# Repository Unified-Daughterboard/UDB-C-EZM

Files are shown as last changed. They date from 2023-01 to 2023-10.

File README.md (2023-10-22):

# Unified Daughterboard C Series - EZM variant

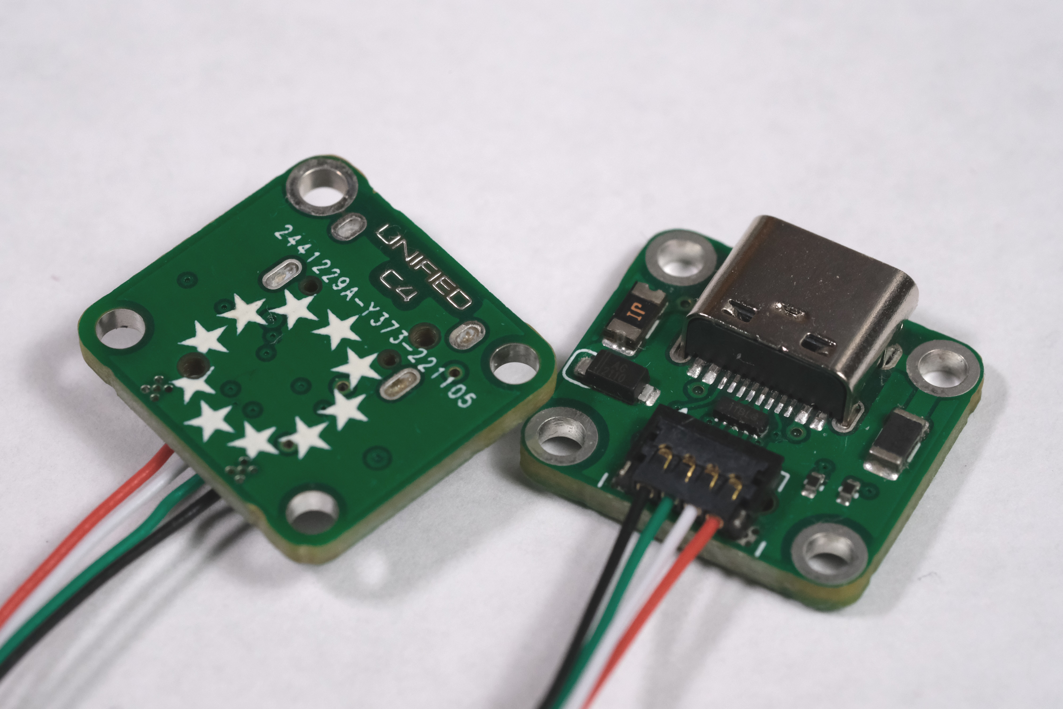
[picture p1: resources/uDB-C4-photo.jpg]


## Introduction
The Unified Daughterboard Project is an open standard to unify the USB daughterboards used in custom mechanical keyboard projects.  
The Unified Daughterboard allows designers to easily implementing electrical protection via a tested proven PCB, and allows users to maintain and repair their keyboards in the future.  
  
For more details on the Unified Daughterboard project, see the [main website](https://unified-daughterboard.github.io/).

## C Series

The C5 daughterboard is the current most recent revision to the classic square form-factor daughterboard, with its roots in the C1 which was designed to be compatible with Wilba's keyboards.
The daughterboard features the following:

- ESD protection, overcurrent protection, overvoltage protection, shielding noise decoupling, and single-path grounding to chassis functionality
- Two variants: The new Molex Pico-EZmate and the classic JST-SH
- 1:1 connector pinout to retain compatibility with existing PCBs
- Same form factor as the older C3 series, allowing for daughterboard upgrades
  
**This is the EZM variant using the Pico-EZMate connector.**  
For background on why two variants exist, please see the [announcement post](https://unified-daughterboard.github.io/#/announcements/announcement-20231022).

The C5 version of the daughterboard was split into two versions: C-JSH and C-PEM, repectively pertaining to versions using the JST-SH connector and the MOLEX EZMate connector.

## Using the C series uDB in your design
Please [visit the docs](https://unified-daughterboard.github.io/) for detailed implementation references and notices.  

## Previews
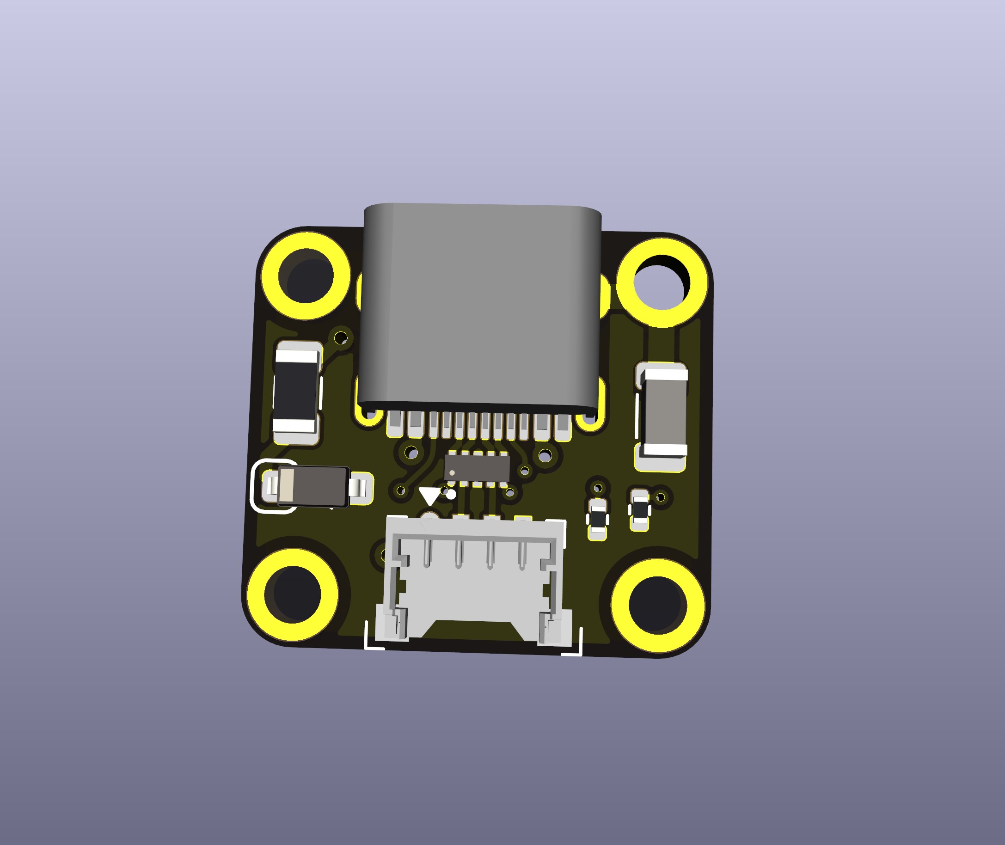
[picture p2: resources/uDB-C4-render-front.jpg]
Render

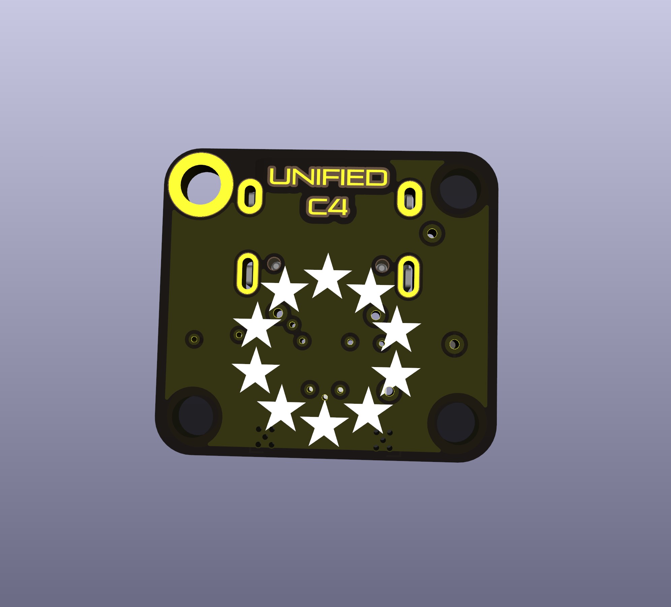
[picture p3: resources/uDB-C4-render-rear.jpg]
Render


## Credits
- [Gondolindrim](https://github.com/Gondolindrim)
- [hineybush](https://hineybush.com/)
- [ai03](https://ai03.com/)
- [GEON](https://geon.works/)
- [Sleepdealer](https://sleepdealer.xyz)
- [Xelus](https://xelus.me)
- [James (AKB)](https://alchemistkeyboards.com/)
- [kkatano](https://github.com/kkatano)
- [ToastyStoemp](https://vwolf.be)
- [Upas](https://cannonkeys.com)

C3 Unified:
- [Wilba](https://wilba.tech)
- Xondat
- [aeryxz](https://github.com/aeryxz)
- [Maximillian](https://github.com/Maximillian)

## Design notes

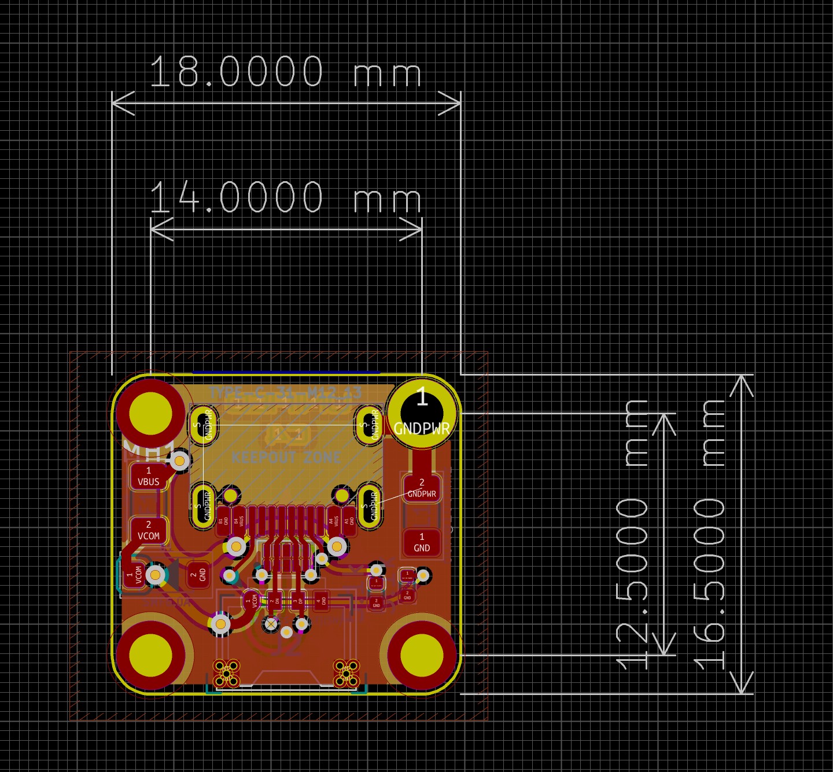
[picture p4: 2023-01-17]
resources/uDB-C4-dimens.jpg

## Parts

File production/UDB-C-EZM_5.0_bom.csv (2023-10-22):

Designator | Value | Footprint | LCSC Part Number | Manufacturer | Manufacturer Part Number | Package
D1 | SMF6.0A | D_SOD-123 | C708002 | FTR | SMF6.0A | SOD-123FL
F1 | ASMD1206-150 | Fuse_1206_3216Metric | C135342 | Shenzhen JDT Fuse | ASMD1206-150 | F1206
J1 | TYPE-C-31-M12_13 | TYPE-C-31-M-12 | C165948 | Korean Hroparts | TYPE-C-31-M-12
J2 | X1224WRS-04-LPV01 | PicoEZMate-Reinforced-Alt | C528030 | XKB Connectivity | X1224WRS-04-LPV01
R1 R2 | 5.1k | R_0402_1005Metric | C25905 | Uniroyal | 0402WGF5101TCE | R0402
U1 | TPD4E05U06DQAR | USON-10_2.5x1.0mm_P0.5mm | C138714 | Texas Instruments | TPD4E05U06DQAR | uSON-10

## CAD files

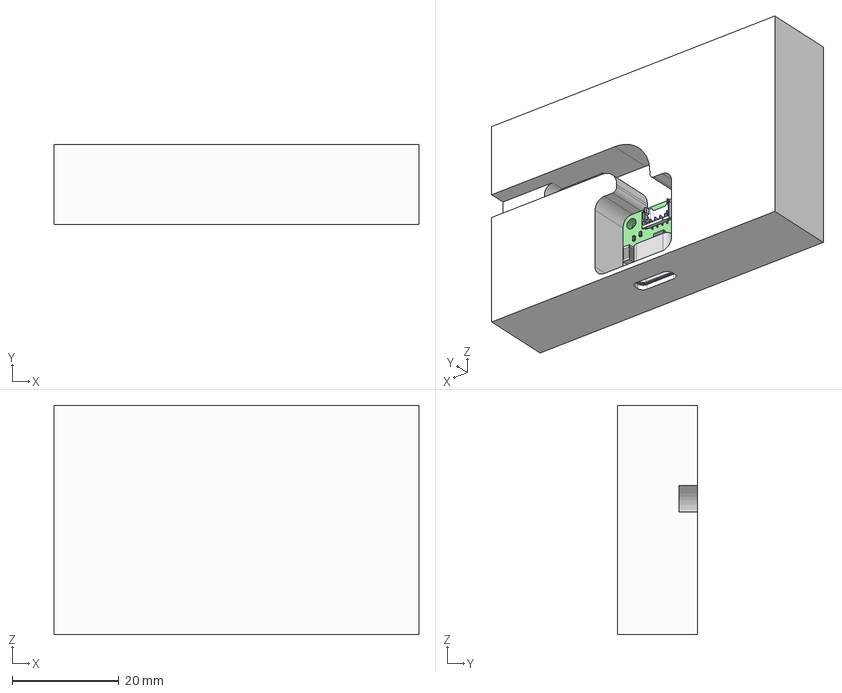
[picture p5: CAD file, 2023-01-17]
resources/uDB-C4-implementation-example.step
68.5 x 15.0 x 43.0 mm
_autosave-UDB PCB

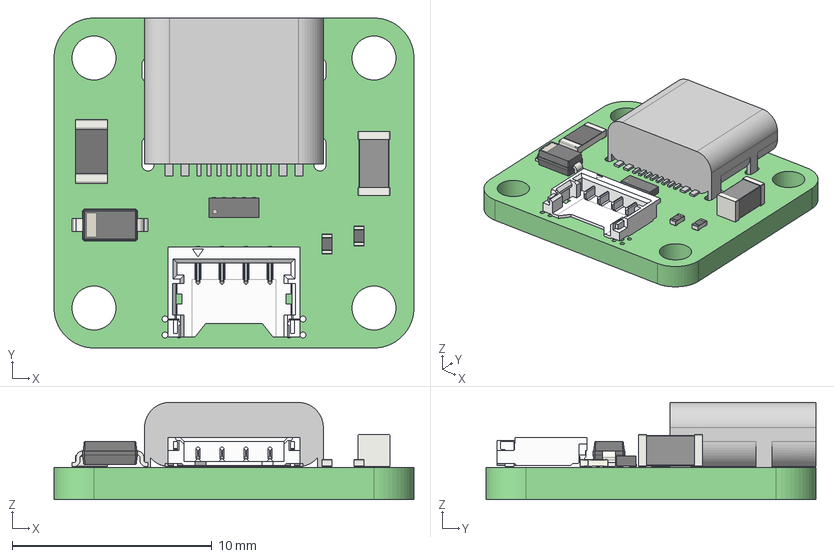
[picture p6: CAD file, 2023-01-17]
uDB-C4-3D-model.step
18.0 x 16.5 x 4.86 mm
_autosave-UDB PCB

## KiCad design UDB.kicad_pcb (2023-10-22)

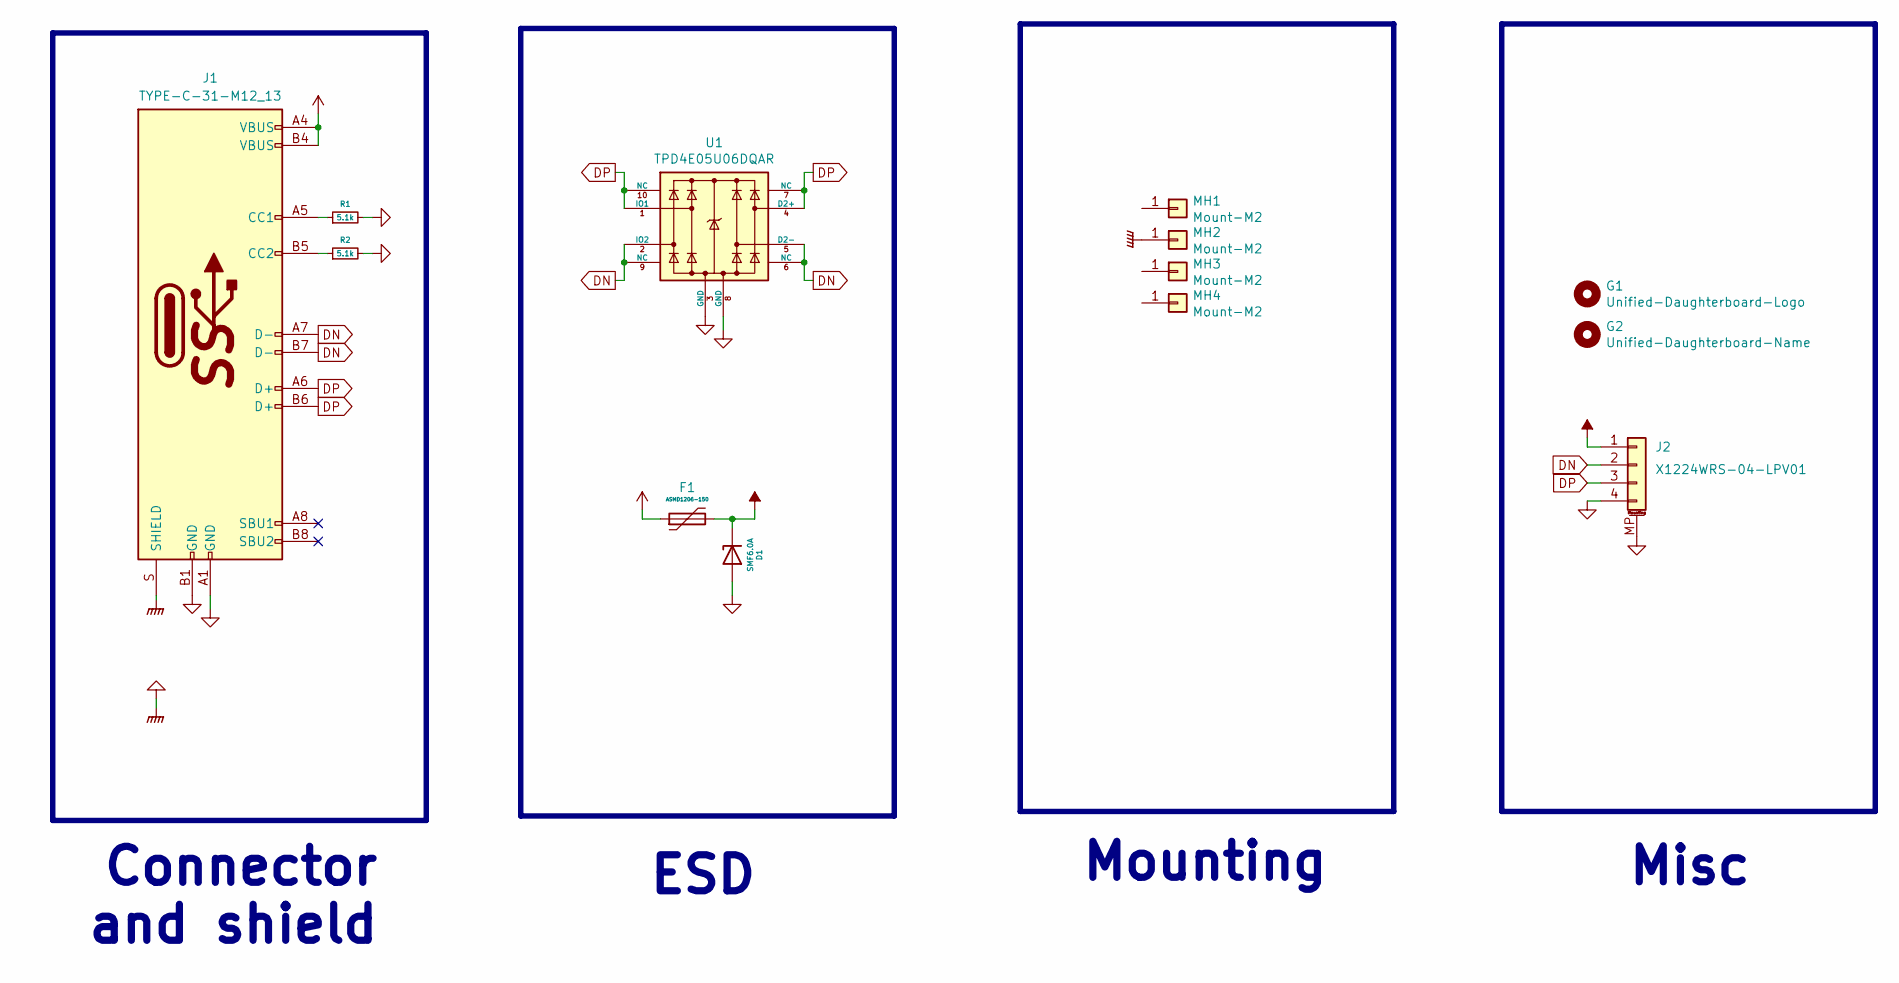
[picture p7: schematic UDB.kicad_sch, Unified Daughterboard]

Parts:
D1: SMF6.0A; D_SOD-123; Manufacturer Part Number SMF6.0A; LCSC Part Number C708002
F1: ASMD1206-150; Fuse_1206_3216Metric; Manufacturer Part Number ASMD1206-150; LCSC Part Number C135342
G1: Unified-Daughterboard-Logo; Unified-Daughterboard-Logo.pretty
G2: Unified-Daughterboard-Name; Unified-Daughterboard-Name.pretty
J1: TYPE-C-31-M12_13; TYPE-C-31-M-12; Manufacturer Part Number TYPE-C-31-M-12; LCSC Part Number C165948
J2: X1224WRS-04-LPV01; PicoEZMate-Reinforced-Alt; Manufacturer Part Number X1224WRS-04-LPV01; LCSC Part Number C528030
MH1, MH2, MH3, MH4: Mount-M2; Generic-Mounthole
R1: 5.1k; R_0402_1005Metric; Manufacturer Part Number 0402WGF5101TCE; LCSC Part Number C25905
R2: 5.1k; R_0402_1005Metric
U1: TPD4E05U06DQAR; USON-10_2.5x1.0mm_P0.5mm; Manufacturer Part Number TPD4E05U06DQAR; LCSC Part Number C138714

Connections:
DN: J1.A7 (D-), J1.B7 (D-), J2.2, U1.2 (IO2), U1.5 (D2-), U1.6 (NC), U1.9 (NC)
DP: J1.A6 (D+), J1.B6 (D+), J2.3, U1.1 (IO1), U1.4 (D2+), U1.7 (NC), U1.10 (NC)
GND: D1.2 (A), J1.A1 (GND), J1.B1 (GND), J1.S (SHIELD), J2.4, J2.MP (MountPin), MH2.1, R1.2, R2.2, U1.3 (GND), U1.8 (GND)
unnamed: J1.A5 (CC1), R1.1
unnamed: J1.B5 (CC2), R2.1
VBUS: F1.1, J1.A4 (VBUS), J1.B4 (VBUS)
VCOM: D1.1 (K), F1.2, J2.1

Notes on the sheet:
Connector and shield
Misc
Mounting
ESD

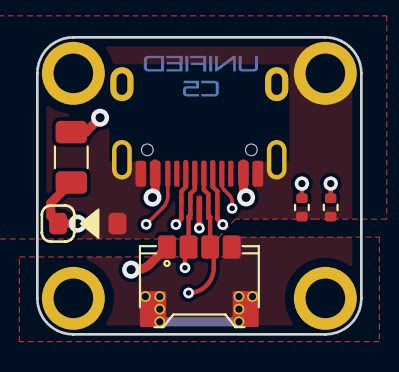
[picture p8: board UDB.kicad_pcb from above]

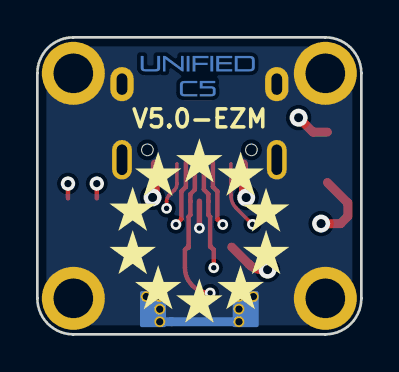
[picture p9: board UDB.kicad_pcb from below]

Board: 4 copper layers, 18.0 x 16.5 mm, 13 parts (2 on the bottom side), 7 nets.

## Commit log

2022-10-14 Major redesign, almost complete routing, new logo
    [UDB.kicad_pcb, UDB.kicad_sch]
2022-10-14 Skew phase adjustment for outer USB diff pair
    [UDB.kicad_pcb, UDB.kicad_sch]
2022-11-01 Edit component metadata, final checks, release
    [UDB.kicad_pcb, UDB.kicad_sch]
2022-12-15 Swap footprint
    [UDB.kicad_pcb, UDB.kicad_sch]
2023-01-17 Add prod files and 3D model
    [UDB_C4_bom_JLC.csv, UDB_C4_posfile.csv, uDB-C4-3D-model.step]
2023-01-17 Fix missing uson chip in 3D model; add implementation example
    [uDB-C4-3D-model.step, uDB-C4-implementation-example.step]
2023-02-24 Retune trace thickness and USB data phase skew; plate connector mounting points to GND signal
    [UDB.kicad_pcb]
2023-03-29 Add 4.1 silkscreen indicators to PCB
    [UDB.kicad_pcb]
2023-04-11 Update fuse part number in production BOM
    [UDB_C4_bom_JLC.csv]
2023-05-09 Update prod resources to 4.1
    [UDB_C4.1_bom_JLC.csv, UDB_C4.1_posfile.csv, UDB_C4_bom_JLC.csv]
2023-08-19 New C5 version files, remove old prod files
    [UDB.kicad_pcb, UDB.kicad_sch, UDB_C4.1_bom_JLC.csv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]
2023-10-22 Add C5 logo and -EZM marking; update prod files
    [UDB-C-EZM_5.0_bom.csv, UDB-C-EZM_5.0_posfile.csv, UDB.kicad_pcb]
